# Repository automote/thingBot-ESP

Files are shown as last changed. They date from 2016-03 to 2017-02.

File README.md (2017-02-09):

# thingBot-ESP

The thingBot-ESP is based on Espressif ESP8266EX Wi-Fi SoC (System on Chip), featuring a Tensilica L106 32-bit micro controller running at 80 MHz. Features include:

 * 802.11 b/g/n protocol
 * Wi-Fi Direct (P2P), soft-AP
 * Integrated TCP/IP protocol stack
 * Wake up and transmit packets in < 2ms
 * Power down leakage current of < 10uA
 * STBC, 1x1 MIMO, 2x1 MIMO
 
## Platform Features

 * [XBee Compatible](https://www.sparkfun.com/datasheets/Wireless/Zigbee/XBee-Dimensional.pdf)
 * Compatible with Arduino IDE
 * 3.3V Vin
 * UART, SPI, I2C
 * On-board RESET
 
## Maintainers

The thingBot-SubGHz is maintained by thingTronics Innovations.

Main contributor:
 * Lovelesh Patel @<lovelesh.patel@thingtronics.com>
 * Poornima Nagesh @<poornima.nagesh@thingtronics.com>

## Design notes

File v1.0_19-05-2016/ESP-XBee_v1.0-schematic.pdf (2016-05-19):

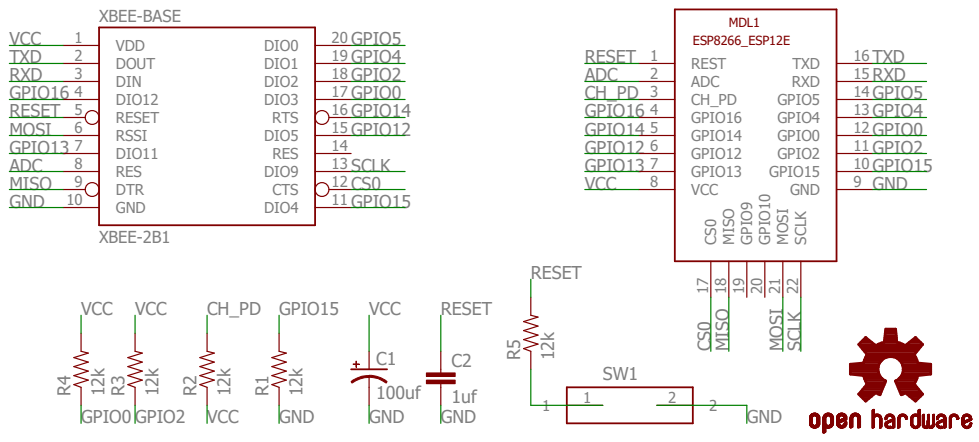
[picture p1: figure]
XBEE-2B1; XBEE-BASE VDD 1 DOUT 2 DIN 3 DIO12 4 RESET 5 RSSI 6 DIO11 7 RES 8 DTR 9; GND 10; DIO4; 11 CTS; 12 DIO9; 13 RES; 14 DIO5; 15 RTS; 16 DIO3; 17 DIO2; 18 DIO1; 19 DIO0; GND; GPIO15; 10 GPIO2; 11 GPIO0; 12 GPIO4; 13 GPIO5; 14 RXD; 15 TXD; 16 REST 1; ADC 2 CH_PD 3 GPIO16 4 GPIO14 5 GPIO12 6 GPIO13 7; RESET; ADC; GPIO16; GPIO14; GPIO12; GPIO13; VCC; VCC VCC; GPIO0; GPIO4; GPIO5; RXD; TXD; GPIO2; GND CS0; MISO; MOSI; SCLK; ESP8266_ESP12E; MDL1

## 19-05-2016 17:21 P:\PCB Design\ESP-XBee\v1.0_19-05-2016\ESP-XBee_v1.0.sch (Sheet: 1/1)

VCC 8 | CS0 17 MISO 18 GPIO⁹ 19 GPIO¹⁰ 20 MOSI 21 SCLK 22 R¹

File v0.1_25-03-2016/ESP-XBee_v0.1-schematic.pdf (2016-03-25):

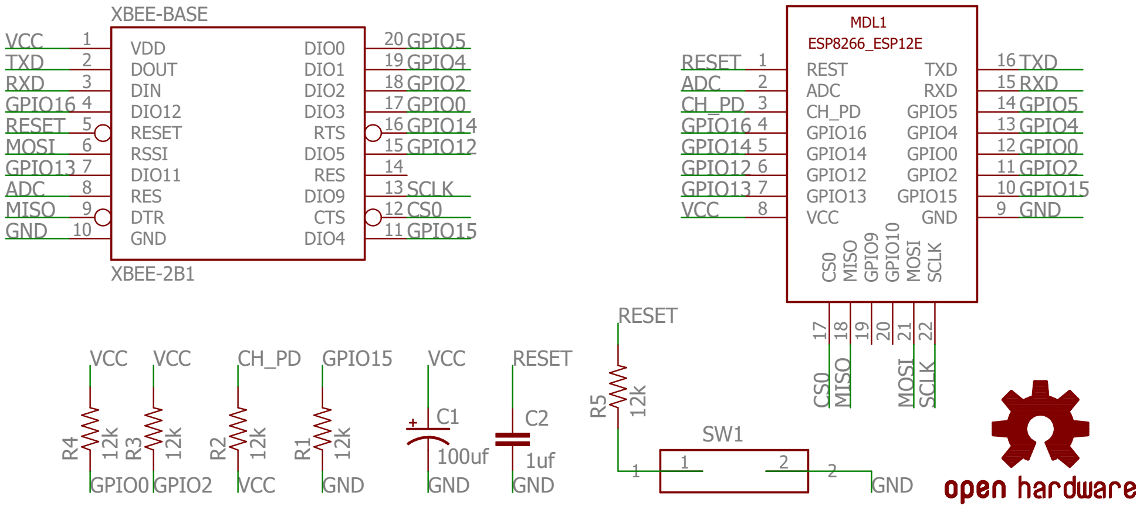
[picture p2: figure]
XBEE-2B1; XBEE-BASE VDD 1 DOUT 2 DIN 3 DIO12 4 RESET 5 RSSI 6 DIO11 7 RES 8 DTR 9; GND 10; DIO4; 11 CTS; 12 DIO9; 13 RES; 14 DIO5; 15 RTS; 16 DIO3; 17 DIO2; 18 DIO1; 19 DIO0; GND; 9 GPIO15; 10 GPIO2; 11 GPIO0; 12 GPIO4; 13 GPIO5; 14 RXD; 15 TXD; 16 REST 1; ADC 2 CH_PD 3 GPIO16 4 GPIO14 5 GPIO12 6 GPIO13 7; RESET; ADC; GPIO16; GPIO14; GPIO12; GPIO13; VCC; VCC VCC; GPIO15; GPIO0; GPIO4; GPIO5; RXD; TXD; GPIO2; GND CS0; MISO; MOSI; SCLK; ESP8266_ESP12E; MDL1

25-03-2016 20:33 f=2.00 P:\PCB Design\ESP-XBee\ESP-XBee.sch (Sheet: 1/1)

VCC 8 | CS0 17 MISO 18 GPIO⁹ 19 GPIO¹⁰ 20 MOSI 21 SCLK 22 R¹

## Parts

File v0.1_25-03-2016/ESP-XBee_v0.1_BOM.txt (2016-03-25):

Partlist exported from P:/PCB Design/ESP-XBee/ESP-XBee.sch at 25-03-2016 20:31

Part      Value        Device                    Package        Description                                             
C1        100uf        CAP_POL1206-KIT           EIA3216-KIT    Capacitor Polarized                                     
C2        1uf          CAP0805                   0805           Capacitor                                               
LOGO3     OSHW-LOGOS   OSHW-LOGOS                OSHW-LOGO-S    Open Source Hardware Logo                               
MDL1                   ESP8266-12EESP8266-ESP12E ESP8266-ESP12E ESP8266-12E with additional I/O and GPIO04/05 corrected 
R1        12k          RESISTOR0805-RES          0805           Resistor                                                
R2        12k          RESISTOR0805-RES          0805           Resistor                                                
R3        12k          RESISTOR0805-RES          0805           Resistor                                                
R4        12k          RESISTOR0805-RES          0805           Resistor                                                
R5        12k          RESISTOR0805-RES          0805           Resistor                                                
SW1       434111043826 434111043826              434111043826   WS-TRS-6x3.5 mm SMD Tact Switch, 2 pins                 
XBEE-BASE XBEE-2B1     XBEE-2B1                  XBEE-1         Xbee module footprints

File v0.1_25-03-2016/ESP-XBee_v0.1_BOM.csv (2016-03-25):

Part/Designator | Manufacture Part Number/Seeed SKU | Quantity
C1 | GRM31CR60J107ME39L | 1
C2 | CC0805KKX7R8BB105 | 1
R1 | RC0805FR-0710KL | 1
R2 | RC0805FR-0710KL | 1
R3 | RC0805FR-0710KL | 1
R4 | RC0805FR-0710KL | 1
R5 | RC0805FR-0710KL | 1
SW1 | TS-1188E | 1

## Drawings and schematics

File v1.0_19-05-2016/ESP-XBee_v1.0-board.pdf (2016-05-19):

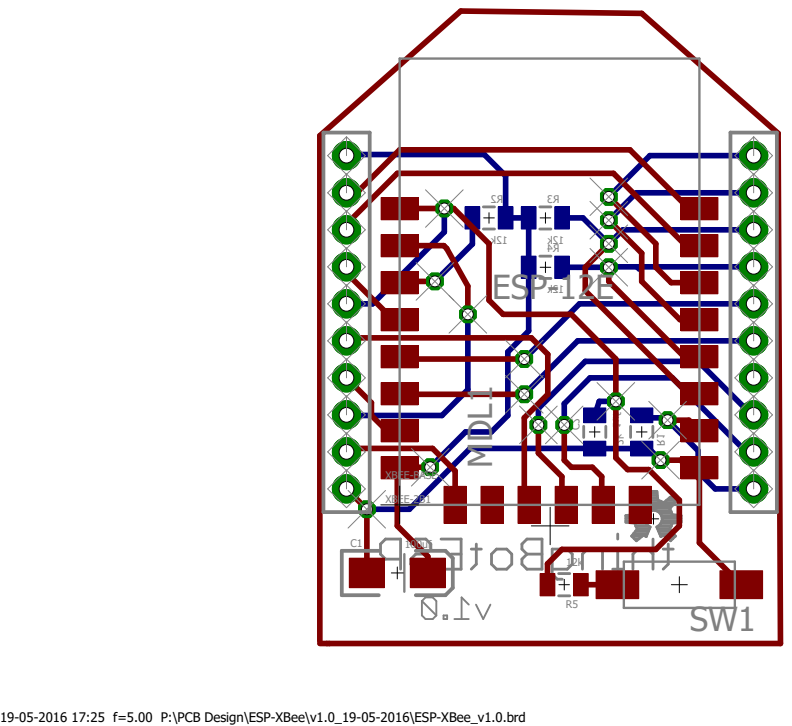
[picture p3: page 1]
19-05-2016 17:25 f=5.00 P:\PCB Design\ESP-XBee\v1.0_19-05-2016\ESP-XBee_v1.0.brd; ESP-12E; XBEE-BASE; XBEE-2B1

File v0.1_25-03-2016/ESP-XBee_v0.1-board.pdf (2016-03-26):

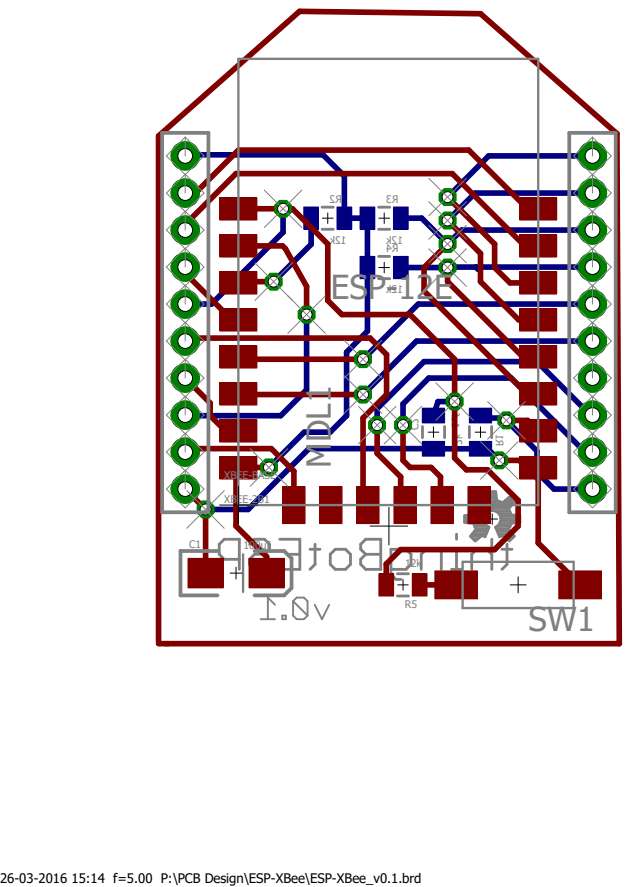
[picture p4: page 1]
ESP-12E; XBEE-BASE; XBEE-2B1

26-03-2016 15:14 f=5.00 P:\PCB Design\ESP-XBee\ESP-XBee_v0.1.brd 1uf 12k

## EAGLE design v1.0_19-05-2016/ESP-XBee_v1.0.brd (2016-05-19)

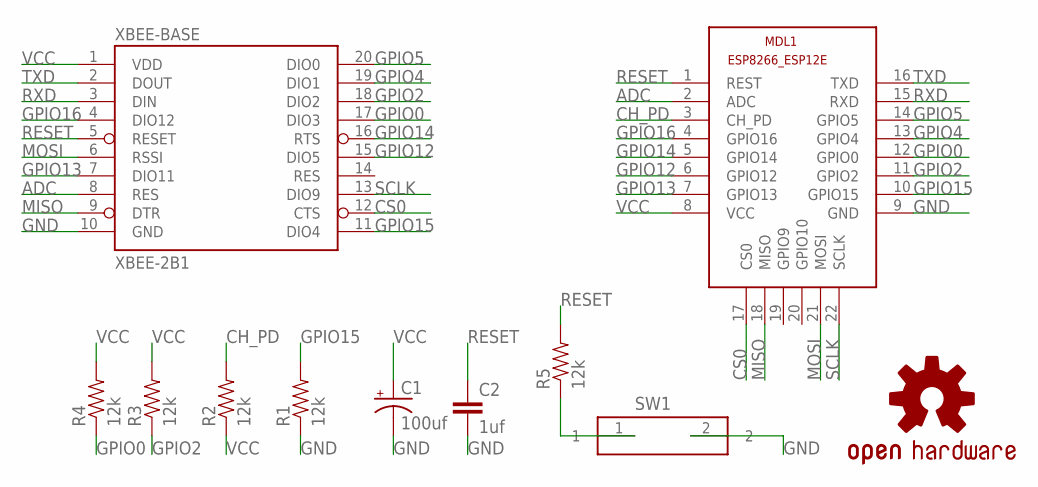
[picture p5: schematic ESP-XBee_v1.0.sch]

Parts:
C1: 100uf; EIA3216-KIT
C2: 1uf; 0805
LOGO3: OSHW-LOGOS; OSHW-LOGO-S
MDL1: ESP8266-12EESP8266-ESP12E; ESP8266-ESP12E
R1, R2, R3, R4, R5: 12k; 0805
SW1: 434111043826
XBEE-BASE: XBEE-2B1; XBEE-1

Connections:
ADC: MDL1.2 (ADC), XBEE-BASE.8 (RES)
CH_PD: MDL1.3 (CH_PD), R2.2
CS0: MDL1.17 (CS0), XBEE-BASE.12 (CTS)
GND: C1.C (-), C2.2, MDL1.9 (GND), R1.1, SW1.2, XBEE-BASE.10 (GND)
GPIO0: MDL1.12 (GPIO0), R4.1, XBEE-BASE.17 (DIO3)
GPIO2: MDL1.11 (GPIO2), R3.1, XBEE-BASE.18 (DIO2)
GPIO4: MDL1.13 (GPIO4), XBEE-BASE.19 (DIO1)
GPIO5: MDL1.14 (GPIO5), XBEE-BASE.20 (DIO0)
GPIO12: MDL1.6 (GPIO12), XBEE-BASE.15 (DIO5)
GPIO13: MDL1.7 (GPIO13), XBEE-BASE.7 (DIO11)
GPIO14: MDL1.5 (GPIO14), XBEE-BASE.16 (RTS)
GPIO15: MDL1.10 (GPIO15), R1.2, XBEE-BASE.11 (DIO4)
GPIO16: MDL1.4 (GPIO16), XBEE-BASE.4 (DIO12)
MISO: MDL1.18 (MISO), XBEE-BASE.9 (DTR)
MOSI: MDL1.21 (MOSI), XBEE-BASE.6 (RSSI)
unnamed: R5.1, SW1.1
RESET: C2.1, MDL1.1 (REST), R5.2, XBEE-BASE.5 (RESET)
RXD: MDL1.15 (RXD), XBEE-BASE.3 (DIN)
SCLK: MDL1.22 (SCLK), XBEE-BASE.13 (DIO9)
TXD: MDL1.16 (TXD), XBEE-BASE.2 (DOUT)
VCC: C1.A (+), MDL1.8 (VCC), R2.1, R3.2, R4.2, XBEE-BASE.1 (VDD)

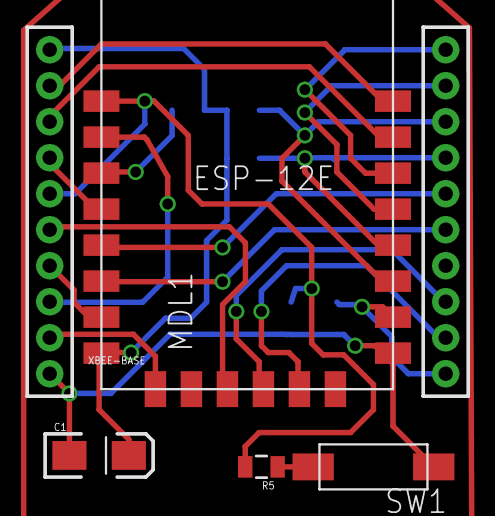
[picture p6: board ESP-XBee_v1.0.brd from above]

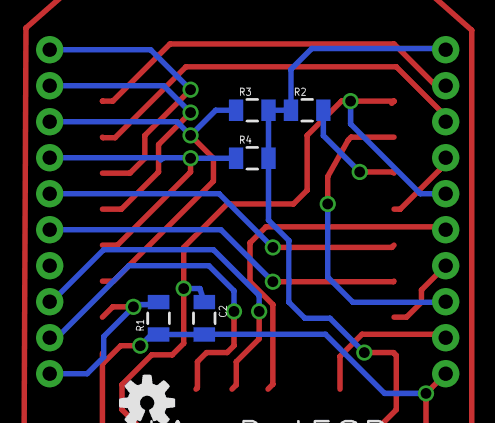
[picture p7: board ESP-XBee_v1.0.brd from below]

Board: 2 copper layers, 11 parts (6 on the bottom side), 21 nets.

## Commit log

2016-03-25 initial routing done.
    Initial routing complete v0.1 ready
    [ESP-XBee.brd, ESP-XBee.sch]
2016-03-25 seeedstudio GERBER generated
    [ESP-XBee.GBL, ESP-XBee.GBO, ESP-XBee.GBP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]
2016-03-25 Revert "seeedstudio GERBER generated"
    This reverts commit 3978db2b9afe7cefcf6061ea9ca2f2ffcfdcaa63.
    [ESP-XBee.GBL, ESP-XBee.GBO, ESP-XBee.GBP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]
2016-03-25 final GERBER generated
    [ESP-XBee.GBL, ESP-XBee.GBO, ESP-XBee.GBP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]
2016-03-25 v0.1 ready for fab
    [ESP-XBee.GBL, ESP-XBee.GBO, ESP-XBee.GBP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]
2016-03-26 added board pdf
2016-05-19 segregated the hardware version into different folders
    [ESP-XBee.GBL, ESP-XBee.GBO, ESP-XBee.GBP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]
2017-02-08 done changes according to new thingbot
    [thingBot-ESPv1P0.sch]
2017-02-08 minor changes
    [thingBot-ESPv1P0.sch]
2017-02-09 schematic verified
    [thingBot-ESPv1P0.sch]
2017-02-09 updated .gitignore for KiCad

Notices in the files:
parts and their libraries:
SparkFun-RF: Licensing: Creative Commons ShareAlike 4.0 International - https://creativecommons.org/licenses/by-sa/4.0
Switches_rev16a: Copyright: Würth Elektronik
